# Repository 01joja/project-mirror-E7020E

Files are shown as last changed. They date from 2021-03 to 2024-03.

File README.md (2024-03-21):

# Nuttali E7020E

We built a gaming mouse in 2 months. Project in Embedded System Design at LTU (E7020E).

Members:  
* Tommy Andersson - anetom-6  (Grade 5)
* Samuel Graden   - samgra-7  (Grade 5)
* Jonas Jacobsson - jonjac-6  (Grade 5)

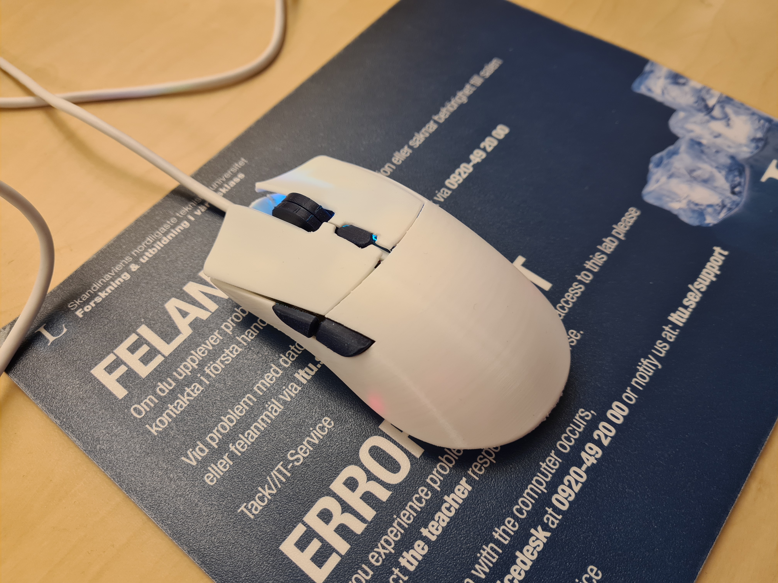
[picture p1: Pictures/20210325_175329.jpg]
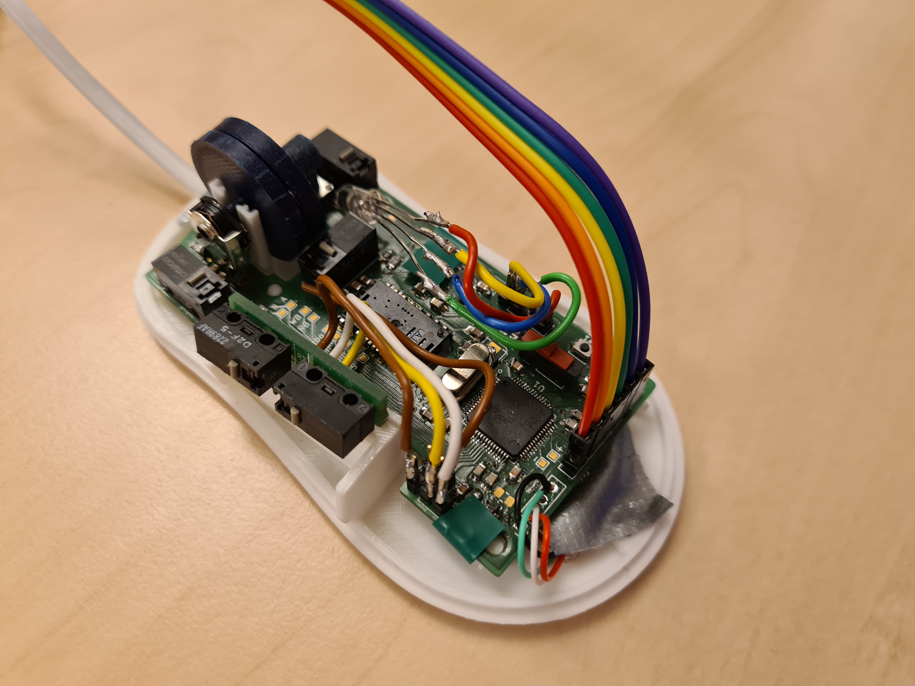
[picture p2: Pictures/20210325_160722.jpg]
 

Name *nuttali* is inspired from *Ochrotomys nuttalli* that is the *Latin* name for [golden mouse](https://en.wikipedia.org/wiki/Golden_mouse).

- Left and right buttons
- Scroll and "scroll button"
- 2 sidbutton
- Considering RGB.

Public found on: [Public](https://github.com/01joja/project-mirror-E7020E)

Course found on: [Course](https://gitlab.henriktjader.com/jonjac-6/nuttali-mirror-of-project)

## Version 0.0.2 is released!

- Side buttons, backwards and forwards now work
- RGB settings can now change mode from the DPI button
- Tested on Linux, Mac and Windows
- Created a customized report

## Version 0.0.1 is released!

The first release of our results in [E7020E](https://www.ltu.se/edu/course/E70/E7020E/E7020E-Design-av-inbyggda-system-1.67927?kursView=kursplan).

- PCB schematics and PCB board where every thing works.
- Rust code that supports basic mouse features:
  - Left, right and scroll click.  
  - Up and down scroll.
  - X and Y movement.
  - USB-communication.

### To be expected in later releases

- Fix error when connecting to some Windows devices.
- Support to change RGB for more values than 0 and 1.
- Fine tuning of sensor.
- A way to change settings by using the terminal.
- New design of scroll wheel.

[Presentation](presentation.md)

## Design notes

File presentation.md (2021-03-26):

# Nuttali Presentation

Created by: 
* Tommy Andderson, anetom-6 (Grade 5)
* Samuel Gradén, samgra-7 (Grade 5)
* Jonas Jacobsson, jonjac-6 (Grade 5)

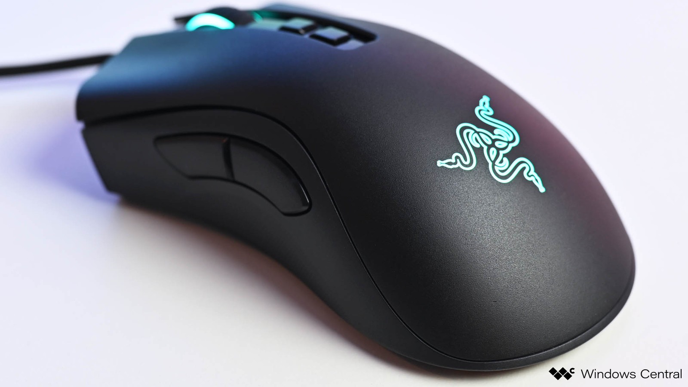
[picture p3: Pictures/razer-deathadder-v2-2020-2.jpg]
Typical gaming mouse

# Requirements specification/features
*   Work as an ordinary mouse
    * Left button
    * Right button
    * Scroll wheel (up and down)
    * Scroll wheel button
*   Create a mouse we could use every day
*   Working on Windows, Mac and Linux
*   Working RGB since it's a gaming mouse
*   Forward and backwards button
*   DPI/Turbo button
*   DPI/Turbo led
*   Changing RGB via software

## Goals

##### Achieved
- Works as an ordinary mouse 
- Create a mouse we could use every day
- Working on Windows, Mac and Linux.
- Working RGB

##### Almost 
- DPI/Turbo button 

##### Not Achieved
- DPI/Turbo Led
- Changing RGB via software

# Design
* Name _Nuttali_
  * Golden mouse in latin.
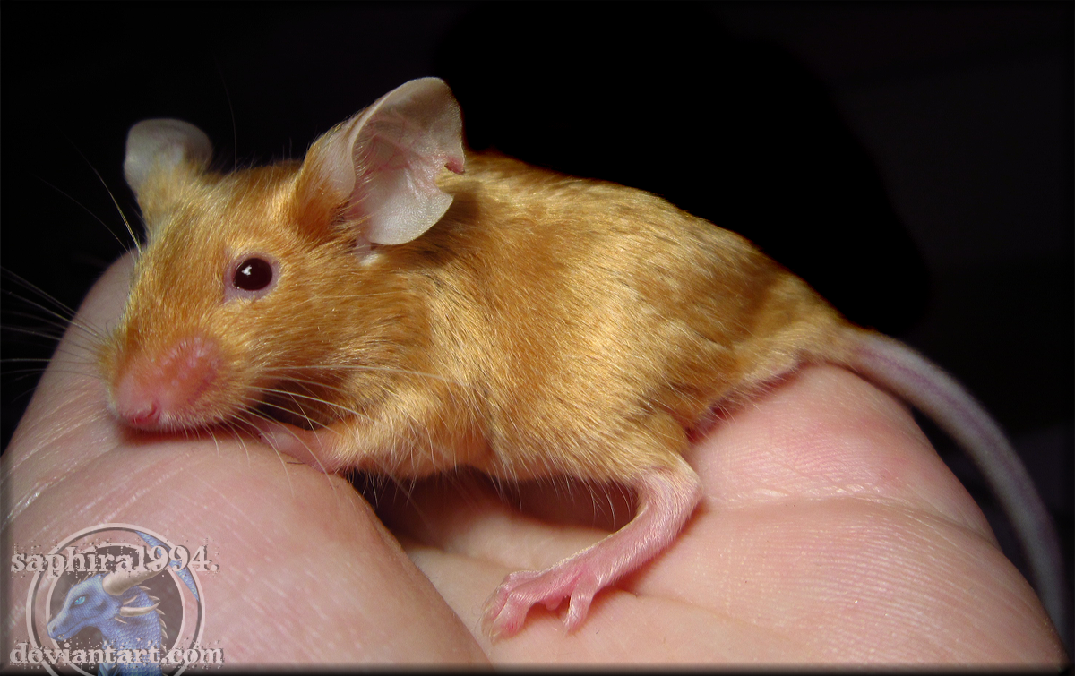
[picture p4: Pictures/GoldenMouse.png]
Golden mouse
 
* 3D-model
  * Logitech G304/G305 
  * [Original design](https://www.thingiverse.com/thing:4084764)  
* Needed changes
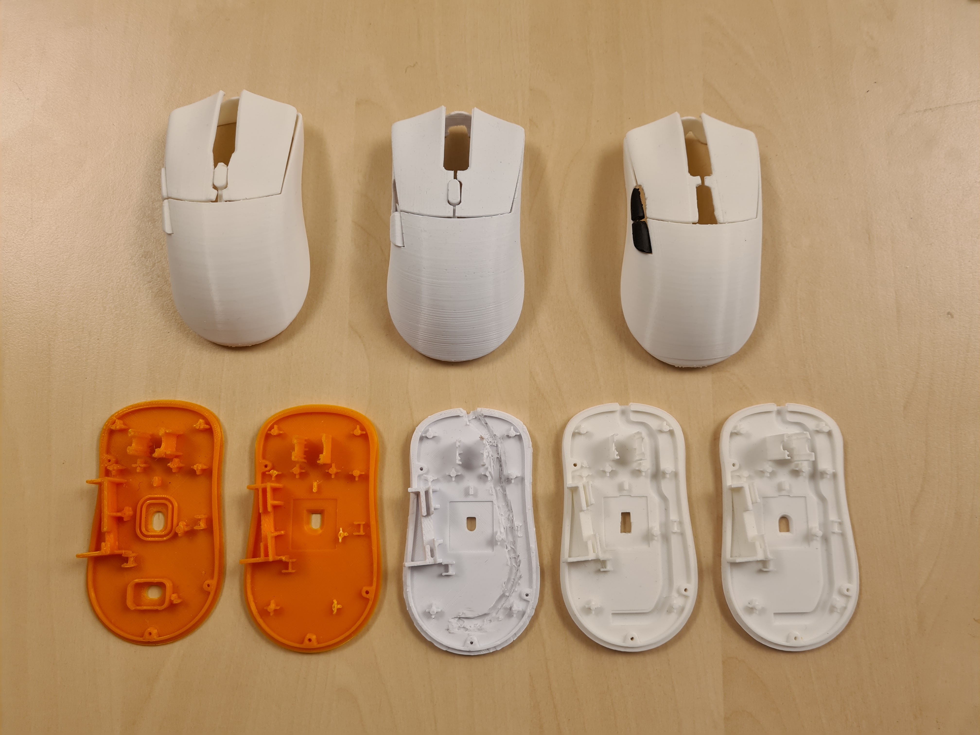
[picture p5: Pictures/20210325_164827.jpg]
All iterations

* Tools used
  * Fusion 360
  * Pursa Mini in Xp-el

# Hardware
* Design choices
* Schematic
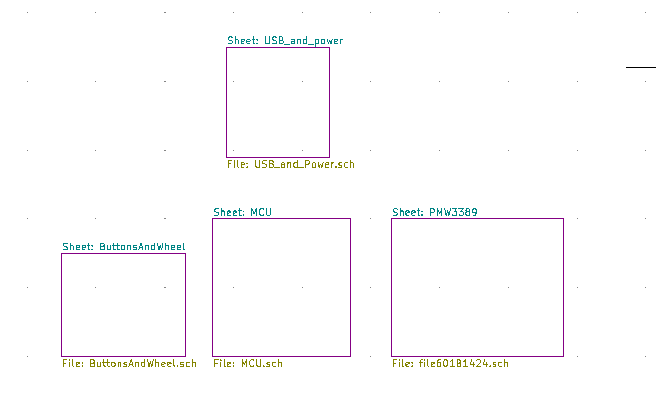
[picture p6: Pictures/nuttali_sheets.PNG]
Sheets
    * 
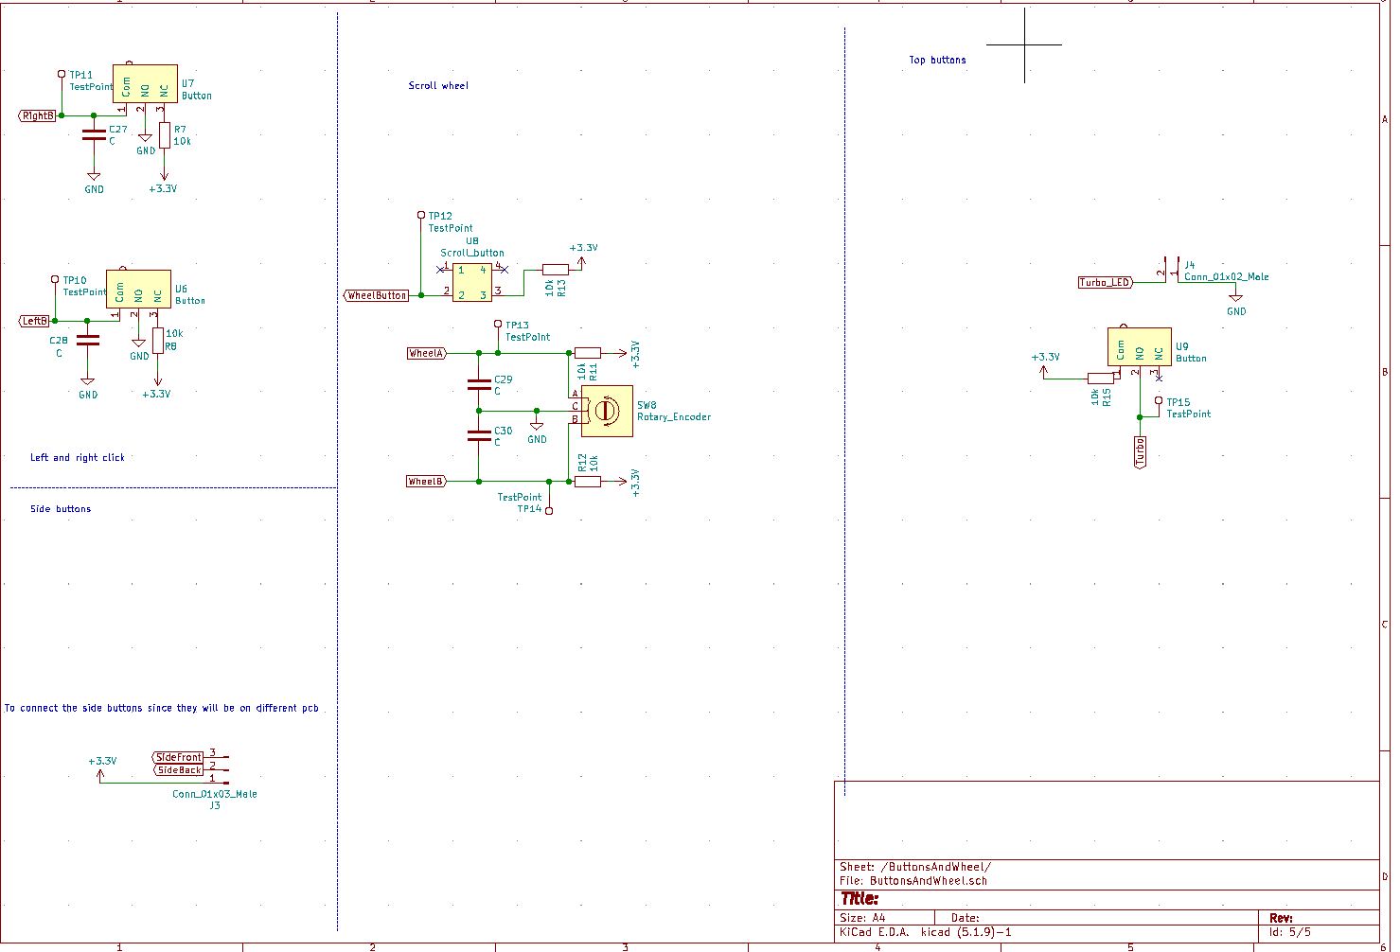
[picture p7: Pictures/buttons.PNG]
Buttons
    * 
* PCB
    * First iteration
    * Second iteration
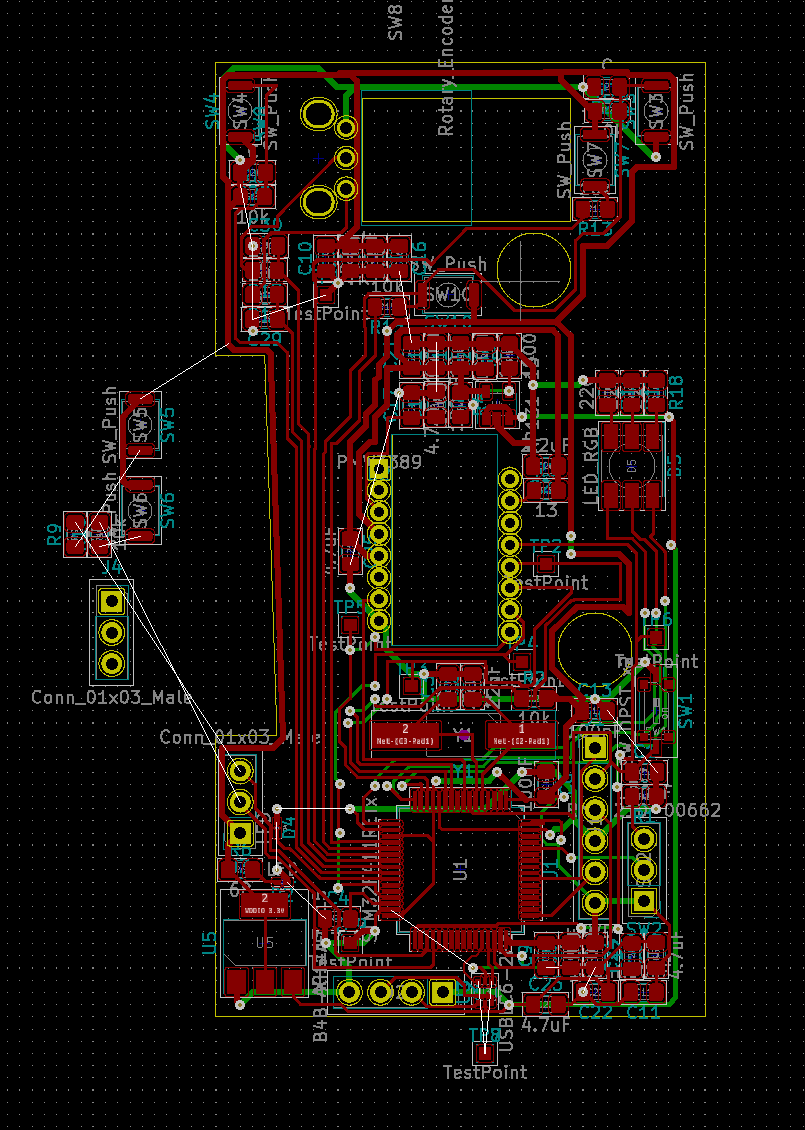
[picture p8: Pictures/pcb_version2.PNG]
Second iteration
    * 
    * Third iteration (final iteration)
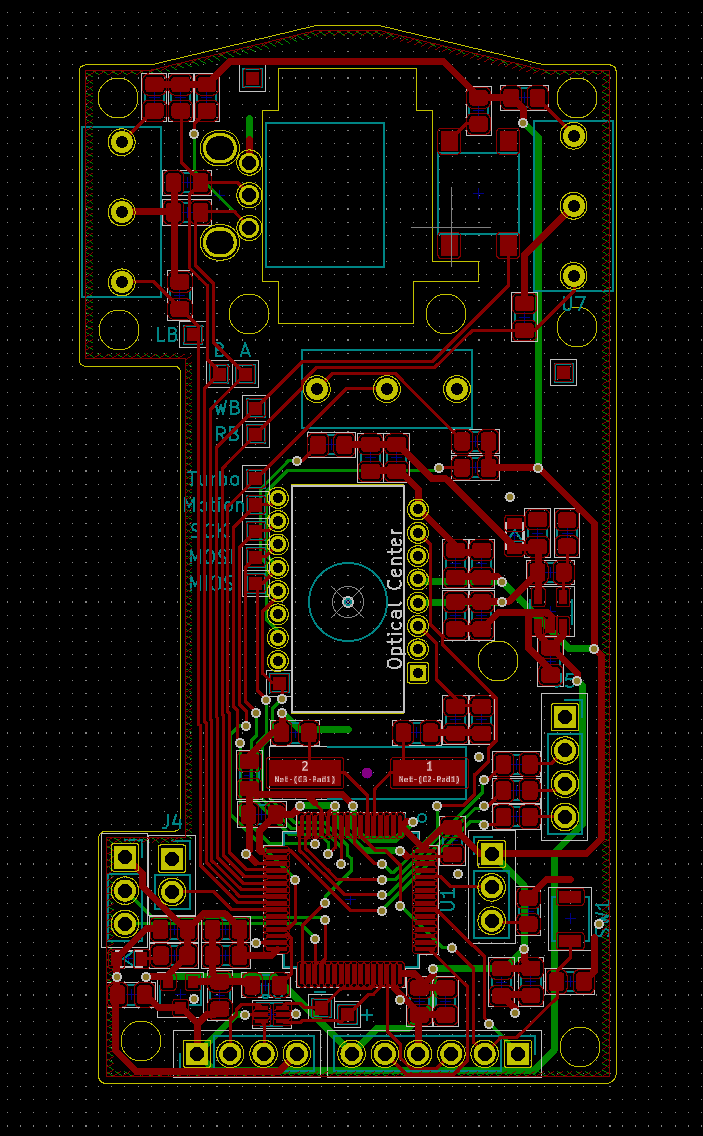
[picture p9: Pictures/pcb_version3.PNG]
Third iteration
    * 
    * Support PCB
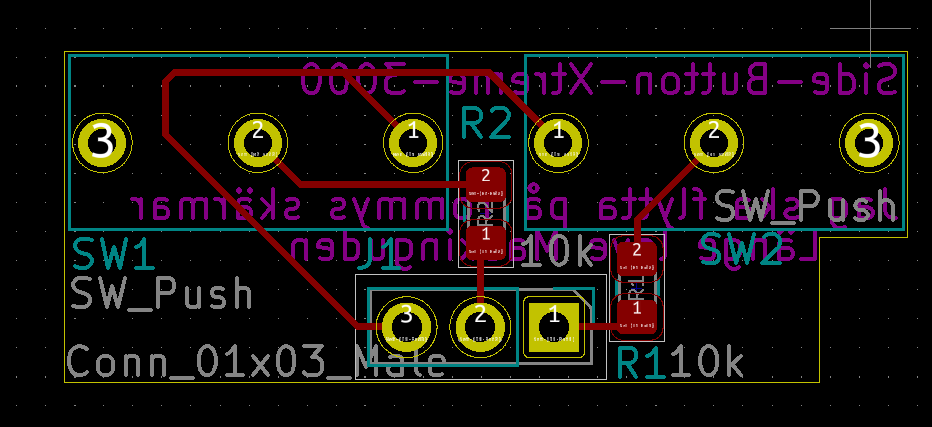
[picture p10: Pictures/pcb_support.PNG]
Support pcb
    * 
* Componets and footprints
    * Prioritized components
    * Customized footprints 
    * Design flaws
    * Under the hood
        * Under the hood 
        
# Result
Nuttali Jonas version
Nuttali Tommy version

# Software

- The computer polls the mouse.
- The mouse button 1, 2 and 3, (left, right, middle) uses HID,
- The x and y posistions gets coverted to 8 bit, and sent using HID.
- Sidebuttons are mouse button 4,5 and works as forward and backwards.

# Testing and validation

* Design test
  * _Dose it feels good?_
* Operation system test
  * Windows 
  * Mac
  * Linux
* Mouse test
  * Tested with light activity for 2 hours
  * Tested gaming
    * CS
  * Tested on mouse testsites
    * https://www.onlinemictest.com/mouse-test/
    * https://www.clickspeedtest.info/mouse-test

## What works?  

- Nearly everything works on the PCB:s.
  - All buttons can be registered.
  - Encoder for the scroll wheel.
  - Sensor.
  - RGB.
- 3D-print:
  - The shell and button alignment works most of the time.
- USB communication.
  - send left, right and scroll click.
  - send up and down scroll.
  - send movement of mouse.

## Issues

- The PCB needs a few tweaks.
  - The footprint for the ESD-protection needs to change. Right now it dose not fit.
  - The footprints for the 3.3V and 1.9 converter should be changed to fit hand soldering. Right now they are troublesome to hand solder.
  - The footprint for the crystal could be a little bit smaller. Right now it takes up too much space.

## Evaluation
##### Major
- The sensor does not always register, our primary guess for the reason is that the sensor is a bit high.
- The scroll button is a bit slow.
- Hardware debounce
- Cabel

##### Minor
- More RGB Leds
- Change the resistor for the leds
- Small changes with the 3d print.
- Bigger mouse
- Scroll Wheel.

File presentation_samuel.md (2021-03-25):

##### Software

- The computer polls the mouse.
- The mouse button 1, 2 and 3, (left, right, middle) uses HID,
- The x and y posistions gets coverted to 8 bit, and sent using HID.
- Sidebuttons are internally and iterates through a set of RBG settings.
- The DPI buttons changes the DPI internally,  

#### Evaluation
##### Major
- The sensor does not always register, our primary guess for the reason is that the sensor is a bit high.
- The scroll button is a bit slow.
- Hardware debounce

##### Minor
- More RBG Leds
- Change the resistor for the leds
- Small changes with the 3d print.
- Bigger mouse
- Scroll Wheel hole should be bigger.

#### Goals

##### Achieved
- Works as an ordinary mouse 
- Create a mouse we could use every day
- Working on Windows, Mac and Linux.
- Working RGB

##### Almost 
- DPI/Turbo button 

##### Not Achieved
- DPI/Turbo Led
- Changing RGB via software

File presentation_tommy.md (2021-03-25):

Typical gaming mouse
# Requirements specification/features
*   Work as an ordinary mouse
    * Left button
    * Right button
    * Scroll wheel (up and down)
    * Scroll wheel button
*   Create a mouse we could use every day
*   Working on Windows, Mac and Linux
*   Working RGB since it's a gaming mouse
*   Forward and backwards button
*   DPI/Turbo button
*   DPI/Turbo led
*   Changing RGB via software

# Hardware
* Design choices
* PCB
    * First iteration
    * Second iteration
    * Third iteration (final iteration)
    * Support PCB
* Componets and footprints
    * Prioritized components
    * Customized footprints 
    * Design flaws

# Testing and validation
*   Operation system test
    * Windows 
    * Mac
    * Linux
*   Mouse test
    * Tested for 1 hour
    * Tested gaming
        * Rainbow six siege
        * CS
    * Tested on mouse testsites
        * https://www.onlinemictest.com/mouse-test/
        * https://www.clickspeedtest.info/mouse-test

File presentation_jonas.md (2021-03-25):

# Jonas Del

## Shell design

The shell we found on the internet that meat our demands where of a [Logitech G305](https://www.logitechg.com/sv-se/products/gaming-mice/g305-lightspeed-wireless-gaming-mouse.910-005283.html).

[Original design](https://www.thingiverse.com/thing:4084764) and [tutorial](https://www.instructables.com/3D-Printed-Gaming-Mouse-G305/).

This mouse shell where not compatible with the PMW3398 sensor and the thickness of our PCB:s where different from the original. This also impacted the buttons and we also got some alignment issues with the side buttons and the corresponding switches. So for us to use it we needed to change a lot of things.

I was responsible for cad and 3D-printing during this project. I had no prior knowledge in any of this so it took quiet some time to get the hang of it. But it where really rewarding and made our project much better.

We used fusion 360 to change the STL files. STL is a vector based format to hold 3D models in and they need to be converted to a workable format before they are changed. It took around 1 week before I could make any changes to the model and around 1 more week until I felt comfterble using fusion 360. 

The learning curve for 3D-printing where not as steep but there where a few things to learn. But now I feel comfterble to do smaller 3D-printing and modeling in my upcoming projects. Xp-el helped me to 

I also designed the scroll wheel from scratch.

*Ask Tommy or Samuel to show the difference between them*

I may have put too much time in to the shell but it gave us a good mouse and with some more changes to the design it could be a good mouse.

## Design of hardware

The hardware design where somewhat inspired form the [G305 PCB](https://www.reddit.com/r/MouseReview/comments/isist1/trimming_guide_for_the_g305_pcb_as_used_in_my/). At least where the buttons goes, the location of the scroll wheel and where the sensor is mounted. Also some of the screw holes came directly from this design. But most of the general layout where things Tommy figured out.

## Testing and validation

During the design of the hardware the only way to test something where with the built in test in KiCad.

Later when we where soldering everything we used the test points in the design frequently. Writing labels next to the test point where really helpful. This made the soldering of the mcu really smooth. Just touch the pin and the test point and you know that you have connection. Touch the pins next to the right pin and you know if two pins are soldered together. Using this way of testing all mcu:s worked first time we programmed them.

The testing and validation of shell and buttons has been *"Dose it feel good?"* and letting our classmates test the mouse.

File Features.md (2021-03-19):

- Höger och vänster knapptryck
- Scroll
- Scrollknapp
- Fram och bakknapp på höger sida.
- Överväger en RGB-LEDs

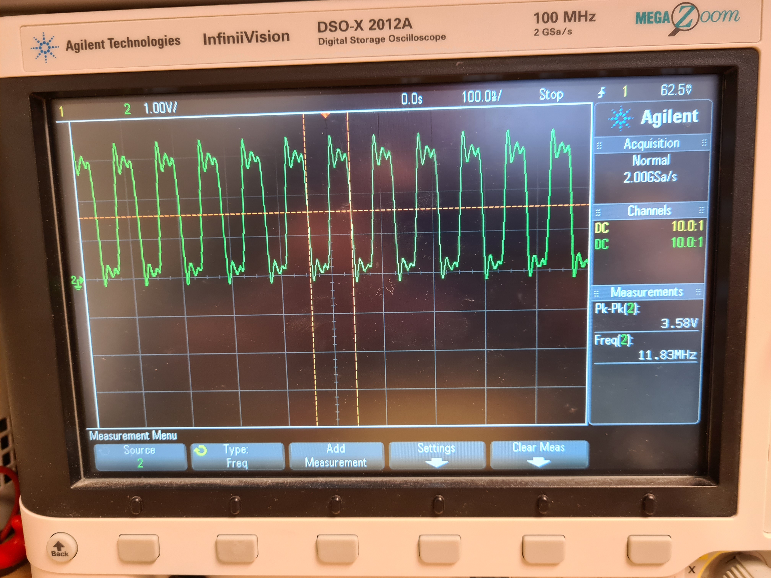
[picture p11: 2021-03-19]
nuttali/examples/pictures/examples_bare_6_48mhz_low_speed.jpg

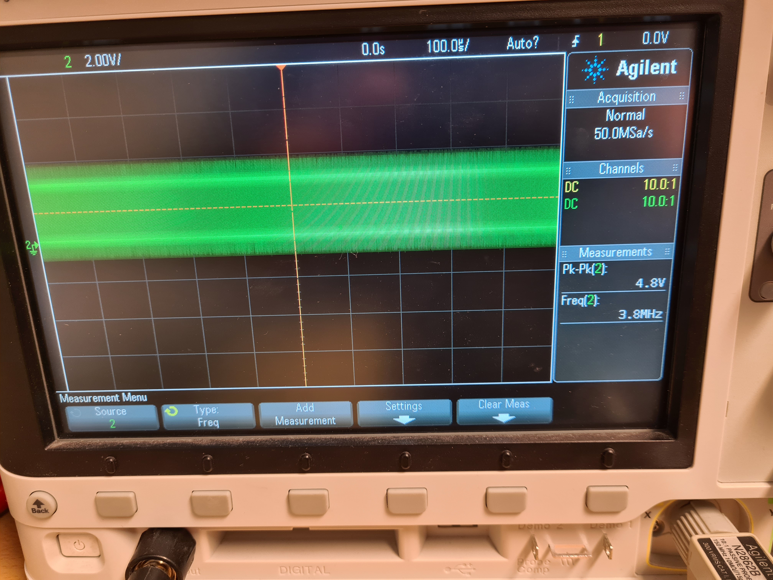
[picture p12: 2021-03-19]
nuttali/examples/pictures/pictures_bare_6_16mhz_high_speed.jpg

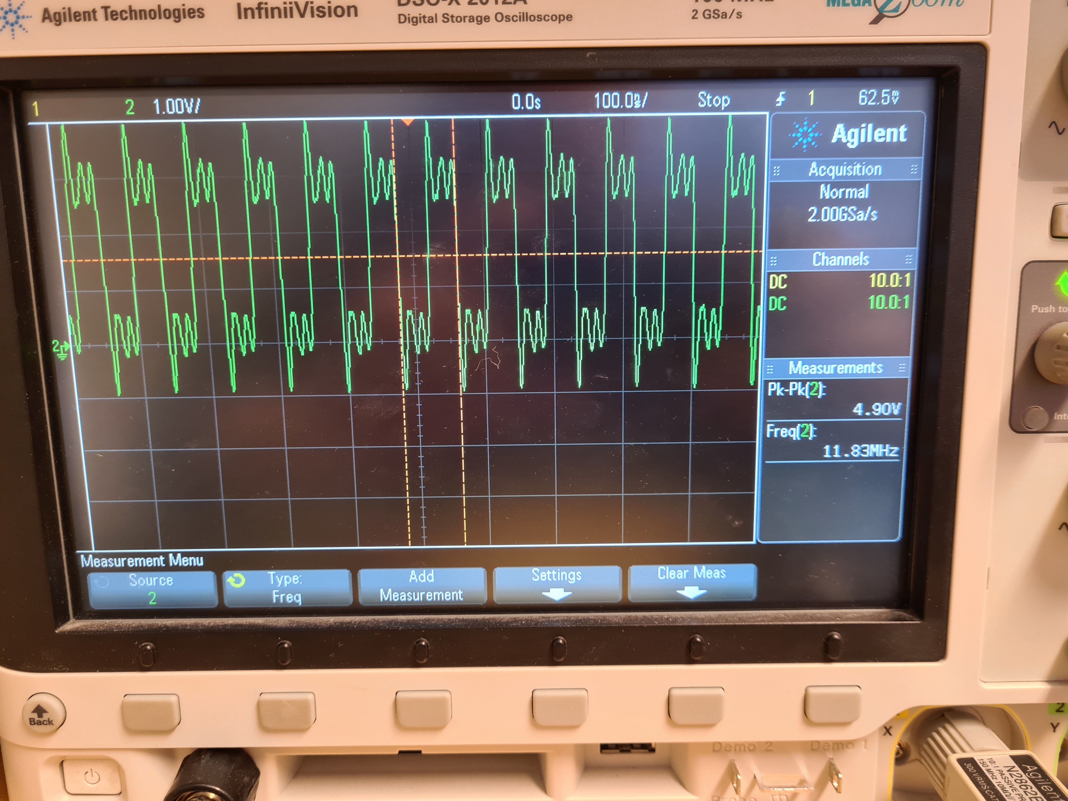
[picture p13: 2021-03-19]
nuttali/examples/pictures/pictures_bare_6_48mhz_high_speed.jpg

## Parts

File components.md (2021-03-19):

[Crystal](https://www.elfa.se/sv/kristall-tht-16mhz-iqd-lfxtal003240/p/17451701?queryFromSuggest=true) 5.18 SEK  
[MCU](https://www.elfa.se/sv/microcontroller-32bit-512kb-lqfp-st-stm32f411ret6/p/30170741?queryFromSuggest=true) 66.63 SEK  
[LED](https://www.elfa.se/en/smd-led-645nm-0805-65cd-30ma-kingbright-kptd-2012surck/p/30118951) 0.9595 SEK  

[6-pins](https://www.elfa.se/en/straight-male-pcb-header-through-hole-rows-contacts-54mm-pitch-rnd-connect-rnd-205-00627/p/30093647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) 0,8435 SEK

Insted of USB-C  
[Straight 4-pin Header](https://www.elfa.se/en/pin-header-single-row-straight-pin-header-plug-positions-5mm-jst-b4b-xh-lf-sn/p/14301996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) 2.01 SEK  
[Mount](https://www.elfa.se/en/crimp-housing-receptacle-socket-positions-5mm-jst-xhp/p/14302034) 1.26 SEK  
[Any old USB-cable](https://www.elfa.se/en/usb-plug-to-usb-mini-pin-plug-cable-8m-black-rnd-connect-rnd-765-00049/p/30125757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) 18.40 SEK  
[Reset button](https://www.elfa.se/en/subminiature-tactile-switch-b3u-1no-5n-3mm-omron-electronic-components-b3u-1000p/p/30171080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) 8.14 SEK
[Or Slide button for reset and boot0](https://www.elfa.se/en/slide-switch-1co-on-on-pcb-through-hole-rnd-components-rnd-210-00662/p/30161239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) 13.20 SEK  

[Mouse Encoder](https://se.rs-online.com/web/p/mechanical-rotary-encoders/7295545) 9.62 SEK  
[Mouse wheel](https://www.aliexpress.com/item/4001130734583.html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,searchweb201602_,searchweb201603_)  

[Mouse Buttons](https://www.elfa.se/en/micro-switch-d2f-5a-1co-47n-pin-plunger-omron-electronic-components-d2f/p/30156583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) 6.84 SEK  
[Scroll Buttons](https://www.elfa.se/en/tactile-switch-1no-on-off-53n-5x6mm-wuerth-elektronik-434121050836/p/30142305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) 6.84 SEK

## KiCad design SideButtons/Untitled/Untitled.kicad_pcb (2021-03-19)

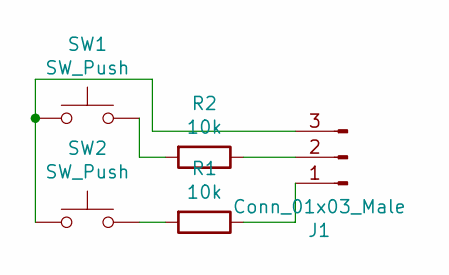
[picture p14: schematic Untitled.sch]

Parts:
J1: Conn_01x03_Male; PinHeader_1x03_P2.54mm_Vertical
R1, R2: 10k; R_0805_2012Metric_Pad1.20x1.40mm_HandSolder
SW1, SW2: SW_Push; D2F-5

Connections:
unnamed: J1.1, R1.1
unnamed: J1.2, R2.1
unnamed: J1.3, SW1.1, SW2.1
unnamed: R1.2, SW2.2
unnamed: R2.2, SW1.2

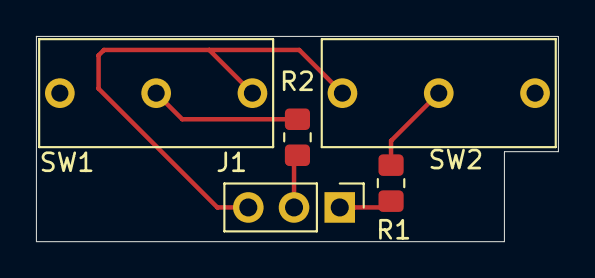
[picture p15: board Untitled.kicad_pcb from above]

Board: 2 copper layers, 29.0 x 11.4 mm, 5 parts (0 on the bottom side), 5 nets.

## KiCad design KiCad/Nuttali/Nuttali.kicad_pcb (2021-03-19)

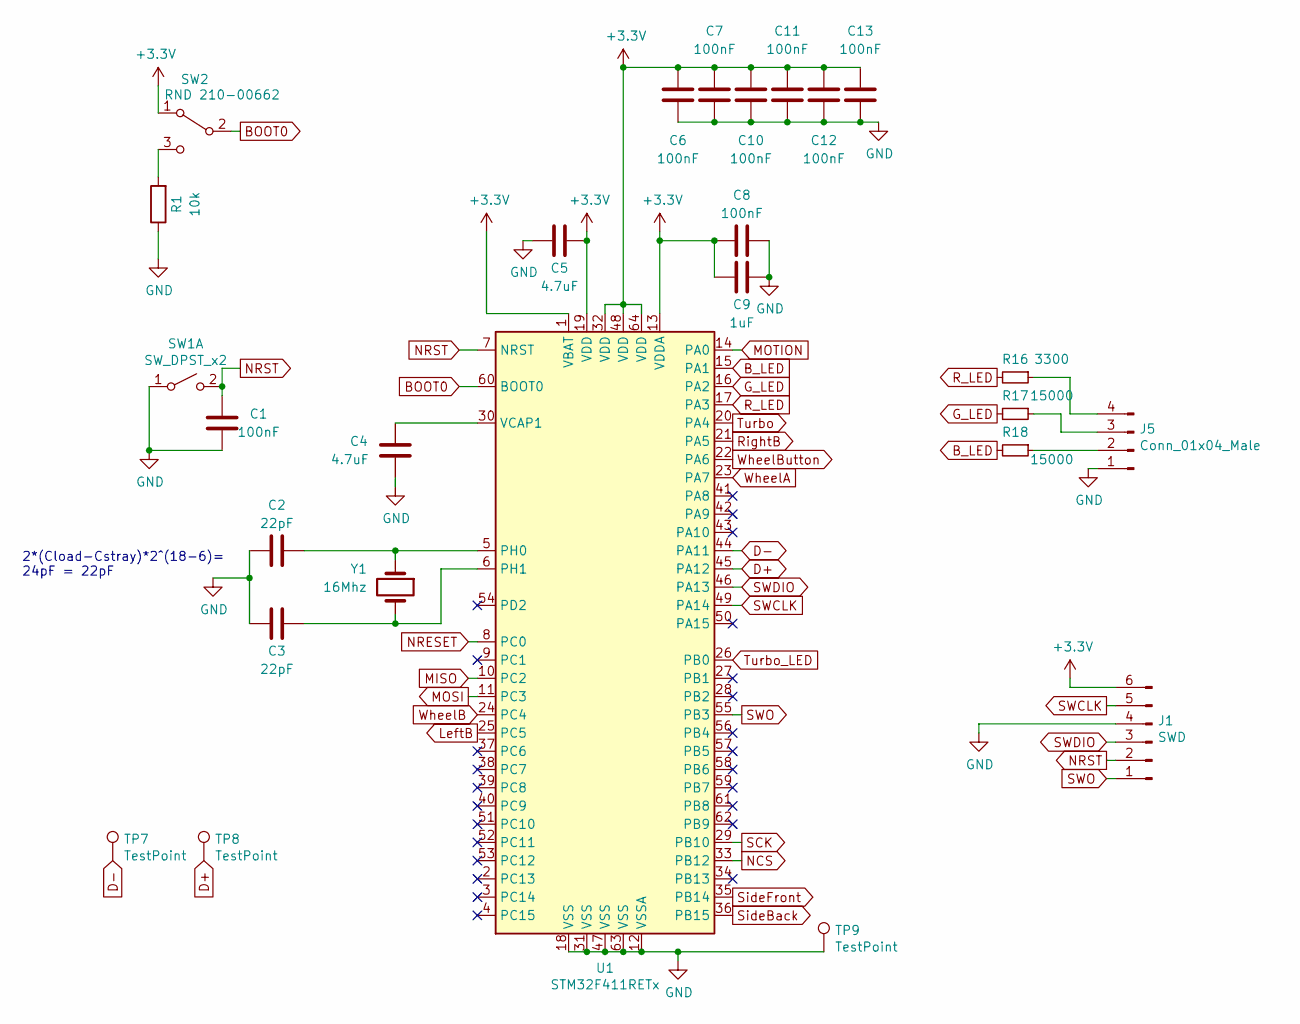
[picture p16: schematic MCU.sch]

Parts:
C1, C6, C7, C8, C10, C11, C12, C13: 100nF; C_0805_2012Metric_Pad1.18x1.45mm_HandSolder
C2, C3: 22pF; C_0805_2012Metric_Pad1.18x1.45mm_HandSolder
C4, C5: 4.7uF; C_0805_2012Metric_Pad1.18x1.45mm_HandSolder
C9: 1uF; C_0805_2012Metric_Pad1.18x1.45mm_HandSolder
J1: SWD; PinHeader_1x06_P2.54mm_Vertical
J5: Conn_01x04_Male; PinSocket_1x04_P2.54mm_Vertical
R1: 10k; R_0805_2012Metric_Pad1.20x1.40mm_HandSolder
R16: 3300; R_0805_2012Metric_Pad1.20x1.40mm_HandSolder
R17, R18: 15000; R_0805_2012Metric_Pad1.20x1.40mm_HandSolder
SW1: SW_DPST_x2; SW_SPST_B3U-1000P
SW2: RND 210-00662; PinHeader_1x03_P2.54mm_Vertical
TP7, TP8, TP9: TestPoint; TestPoint_Pad_1.0x1.0mm
U1: STM32F411RETx; LQFP-64_10x10mm_P0.5mm
Y1: 16Mhz; Crystal_SMD_0603-2Pin_6.0x3.5mm_HandSoldering

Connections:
+3V3: C5.1, C6.2, C7.2, C8.2, C9.2, C10.2, C11.1, C12.1, C13.1, J1.6, SW2.1 (A), U1.1 (VBAT), U1.13 (VDDA), U1.19 (VDD), U1.32 (VDD), U1.48 (VDD), U1.64 (VDD); also elsewhere on the board
BOOT0: SW2.2 (B), U1.60 (BOOT0)
B_LED: R18.2, U1.15 (PA1)
D+: TP8.1, U1.45 (PA12); also elsewhere on the board
D-: TP7.1, U1.44 (PA11); also elsewhere on the board
GND: C1.2, C2.2, C3.2, C4.1, C5.2, C6.1, C7.1, C8.1, C9.1, C10.1, C11.2, C12.2, C13.2, J1.4, J5.1, R1.1, SW1.1 (A), TP9.1, U1.12 (VSSA), U1.18 (VSS), U1.31 (VSS), U1.47 (VSS), U1.63 (VSS); also elsewhere on the board
G_LED: R17.2, U1.16 (PA2)
LeftB: U1.25 (PC5); also elsewhere on the board
MISO: U1.10 (PC2); also elsewhere on the board
MOSI: U1.11 (PC3); also elsewhere on the board
MOTION: U1.14 (PA0); also elsewhere on the board
NCS: U1.33 (PB12); also elsewhere on the board
NRESET: U1.8 (PC0); also elsewhere on the board
NRST: C1.1, J1.2, SW1.2 (B), U1.7 (NRST)
unnamed: C2.1, U1.5 (PH0), Y1.1
unnamed: C3.1, U1.6 (PH1), Y1.2
unnamed: C4.2, U1.30 (VCAP1)
unnamed: J5.2, R18.1
unnamed: J5.3, R17.1
unnamed: J5.4, R16.1
unnamed: R1.2, SW2.3 (C)
R_LED: R16.2, U1.17 (PA3)
RightB: U1.21 (PA5); also elsewhere on the board
SCK: U1.29 (PB10); also elsewhere on the board
SWCLK: J1.5, U1.49 (PA14)
SWDIO: J1.3, U1.46 (PA13)
SWO: J1.1, U1.55 (PB3)
SideBack: U1.36 (PB15); also elsewhere on the board
SideFront: U1.35 (PB14); also elsewhere on the board
Turbo: U1.20 (PA4); also elsewhere on the board
Turbo_LED: U1.26 (PB0); also elsewhere on the board
WheelA: U1.23 (PA7); also elsewhere on the board
WheelB: U1.24 (PC4); also elsewhere on the board
WheelButton: U1.22 (PA6); also elsewhere on the board

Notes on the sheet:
2*(Cload-Cstray)*2^(18-6)= 24pF = 22pF

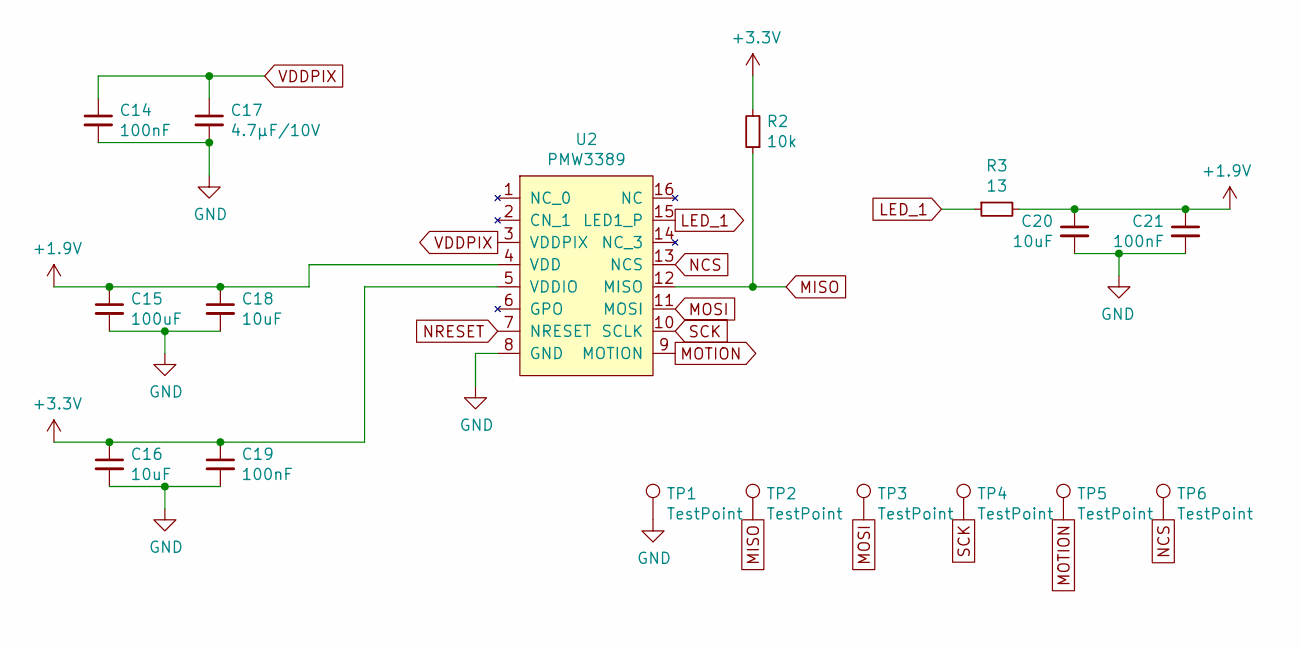
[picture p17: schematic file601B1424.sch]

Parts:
C14, C19, C21: 100nF; C_0805_2012Metric_Pad1.18x1.45mm_HandSolder
C15: 100uF; C_0805_2012Metric_Pad1.18x1.45mm_HandSolder
C16, C18, C20: 10uF; C_0805_2012Metric_Pad1.18x1.45mm_HandSolder
C17: 4.7μF/10V; C_0805_2012Metric_Pad1.18x1.45mm_HandSolder
R2: 10k; R_0805_2012Metric_Pad1.20x1.40mm_HandSolder
R3: 13; R_0805_2012Metric_Pad1.20x1.40mm_HandSolder
TP1, TP2, TP3, TP4, TP5, TP6: TestPoint; TestPoint_Pad_1.0x1.0mm
U2: PMW3389; PMW3389DM-T3QU

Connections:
+1V0: C15.1, C18.1, C20.1, C21.1, R3.2, U2.4 (VDD); also elsewhere on the board
+3V3: C16.1, C19.1, R2.2, U2.5 (VDDIO); also elsewhere on the board
GND: C14.2, C15.2, C16.2, C17.2, C18.2, C19.2, C20.2, C21.2, TP1.1, U2.8 (GND); also elsewhere on the board
LED_1: R3.1, U2.15 (LED1_P)
MISO: R2.1, TP2.1, U2.12 (MISO); also elsewhere on the board
MOSI: TP3.1, U2.11 (MOSI); also elsewhere on the board
MOTION: TP5.1, U2.9 (MOTION); also elsewhere on the board
NCS: TP6.1, U2.13 (NCS); also elsewhere on the board
NRESET: U2.7 (NRESET); also elsewhere on the board
SCK: TP4.1, U2.10 (SCLK); also elsewhere on the board
VDDPIX: C14.1, C17.1, U2.3 (VDDPIX)

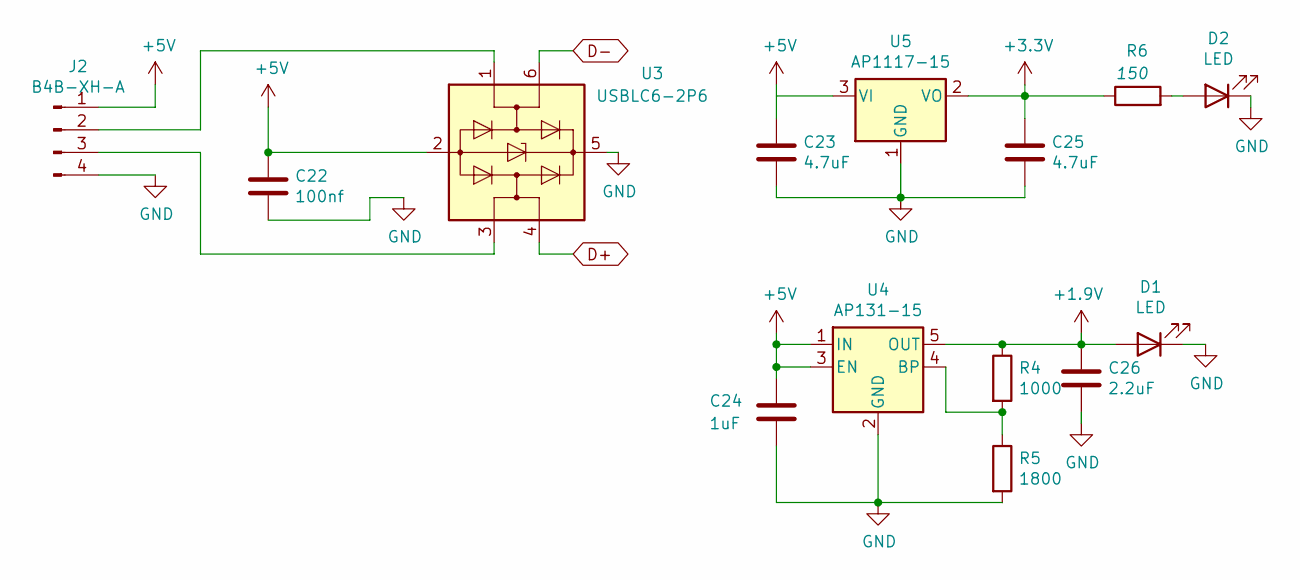
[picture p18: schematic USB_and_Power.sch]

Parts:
C22: 100nf; C_0805_2012Metric_Pad1.18x1.45mm_HandSolder
C23, C25: 4.7uF; C_0805_2012Metric_Pad1.18x1.45mm_HandSolder
C24: 1uF; C_0805_2012Metric_Pad1.18x1.45mm_HandSolder
C26: 2.2uF; C_0805_2012Metric_Pad1.18x1.45mm_HandSolder
D1, D2: LED
J2: B4B-XH-A; PinHeader_1x04_P2.54mm_Vertical
R4: 1000; R_0805_2012Metric_Pad1.20x1.40mm_HandSolder
R5: 1800; R_0805_2012Metric_Pad1.20x1.40mm_HandSolder
R6: 150; R_0805_2012Metric_Pad1.20x1.40mm_HandSolder
U3: USBLC6-2P6; SOT-666_ESD
U4: AP131-15; SOT-23-5
U5: AP1117-15; SOT-23

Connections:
+1V0: C26.1, D1.2 (A), R4.1, U4.5 (OUT); also elsewhere on the board
+3V3: C25.1, R6.1, U5.2 (VO); also elsewhere on the board
+5V: C22.1, C23.1, C24.1, J2.1, U3.2 (GND), U4.1 (IN), U4.3 (EN), U5.3 (VI)
D+: U3.4 (I/O2); also elsewhere on the board
D-: U3.6 (I/O1); also elsewhere on the board
GND: C22.2, C23.2, C24.2, C25.2, C26.2, D1.1 (K), D2.1 (K), J2.4, R5.2, U3.5 (VBUS), U4.2 (GND), U5.1 (GND); also elsewhere on the board
unnamed: D2.2 (A), R6.2
unnamed: J2.2, U3.1 (I/O1)
unnamed: J2.3, U3.3 (I/O2)
unnamed: R4.2, R5.1, U4.4 (BP)

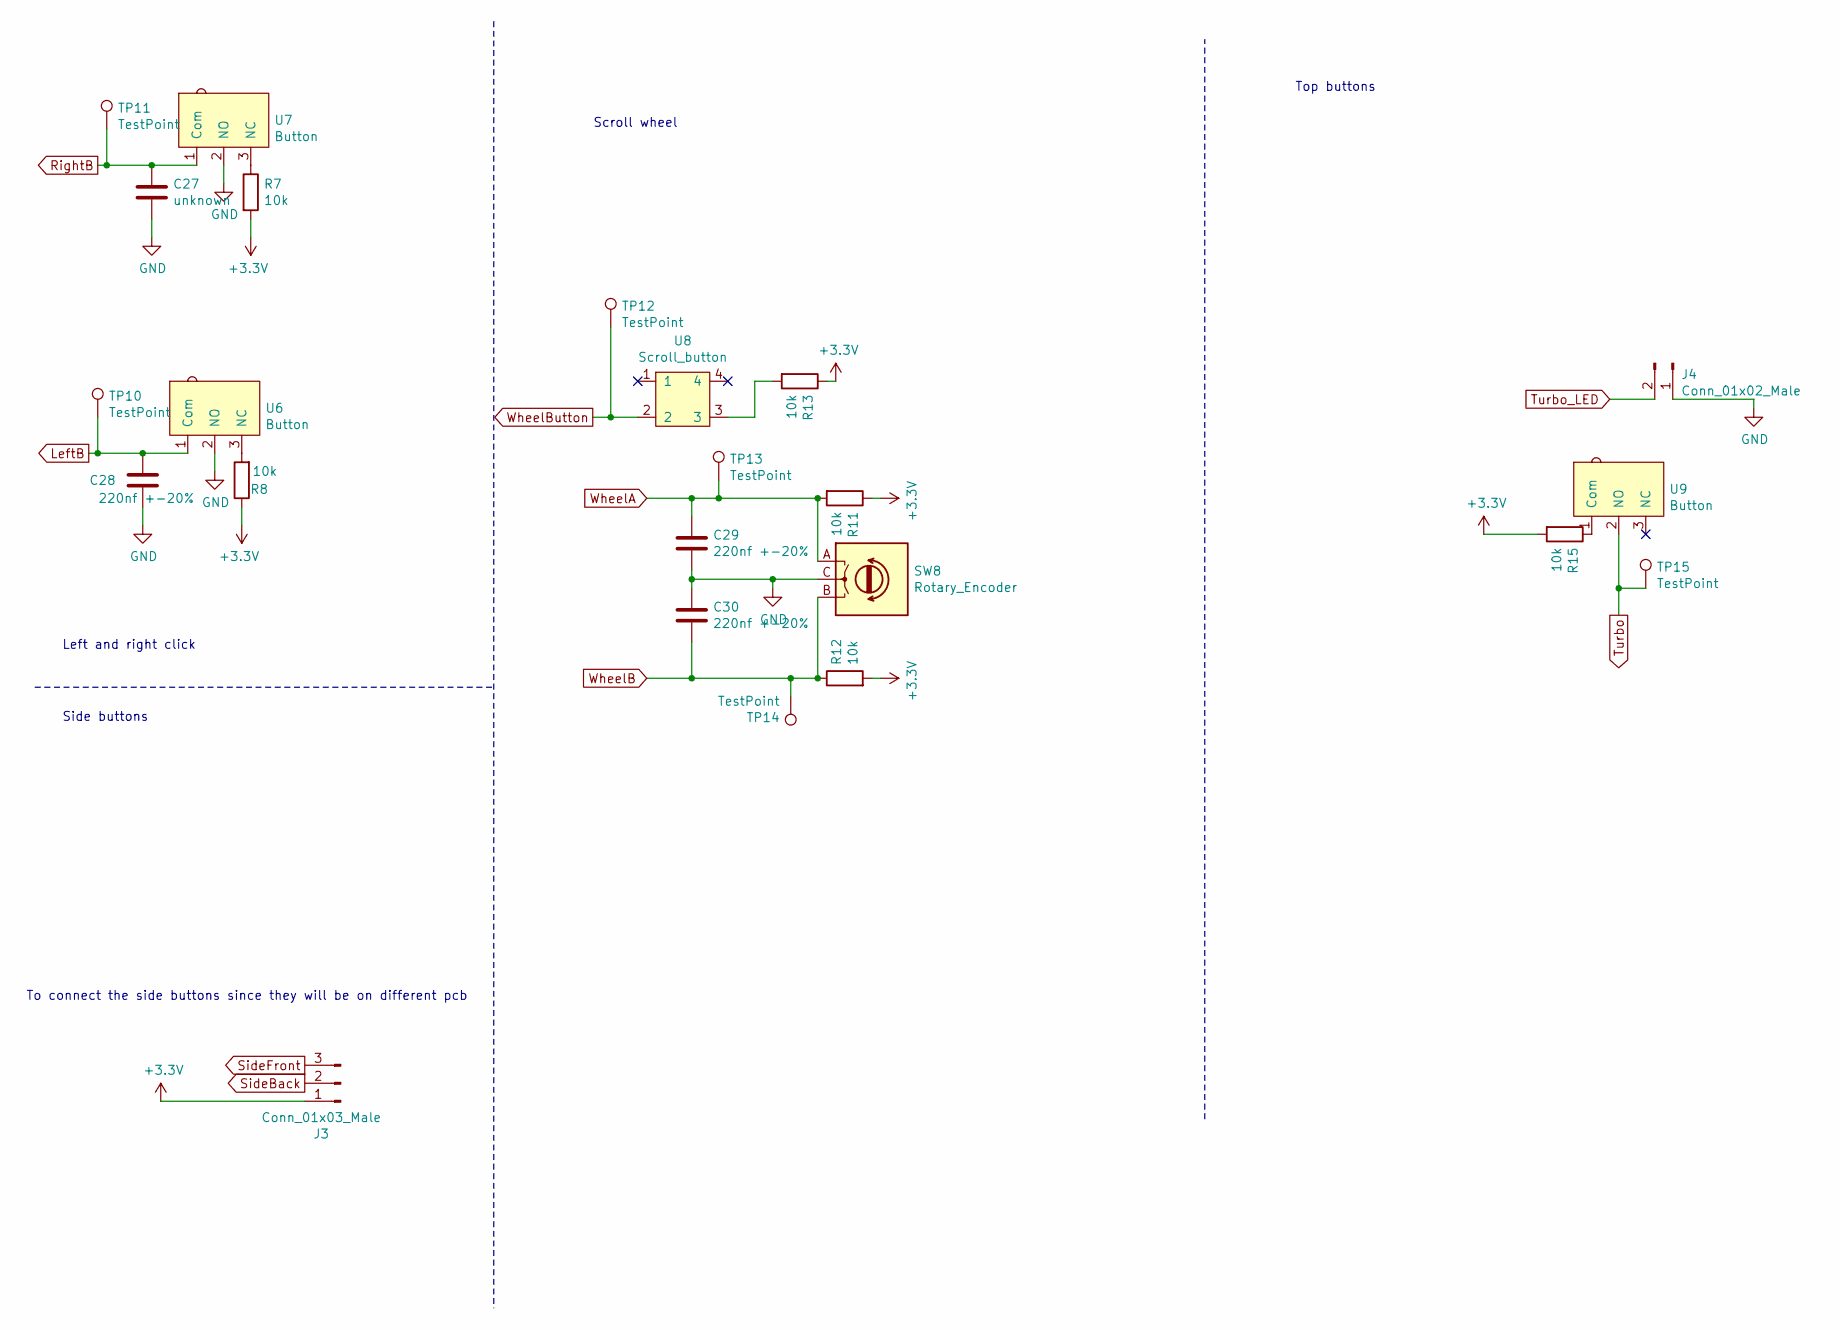
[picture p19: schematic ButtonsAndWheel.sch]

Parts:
C27: unknown; C_0805_2012Metric_Pad1.18x1.45mm_HandSolder
C28, C29, C30: 220nf +-20%; C_0805_2012Metric_Pad1.18x1.45mm_HandSolder
J3: Conn_01x03_Male; PinSocket_1x03_P2.54mm_Vertical
J4: Conn_01x02_Male; PinSocket_1x02_P2.54mm_Vertical
R7, R8, R11, R12, R13, R15: 10k; R_0805_2012Metric_Pad1.20x1.40mm_HandSolder
SW8: Rotary_Encoder; Encoder
TP10, TP11, TP12, TP13, TP14, TP15: TestPoint; TestPoint_Pad_1.0x1.0mm
U6, U7, U9: Button; D2F-5
U8: Scroll_button

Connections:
+3V3: J3.1, R7.2, R8.1, R11.1, R12.2, R13.1, R15.2; also elsewhere on the board
GND: C27.2, C28.2, C29.2, C30.1, J4.1, SW8.C, U6.2 (NO), U7.2 (NO); also elsewhere on the board
LeftB: C28.1, TP10.1, U6.1 (Com); also elsewhere on the board
unnamed: R7.1, U7.3 (NC)
unnamed: R8.2, U6.3 (NC)
unnamed: R13.2, U8.3
unnamed: R15.1, U9.1 (Com)
RightB: C27.1, TP11.1, U7.1 (Com); also elsewhere on the board
SideBack: J3.2; also elsewhere on the board
SideFront: J3.3; also elsewhere on the board
Turbo: TP15.1, U9.2 (NO); also elsewhere on the board
Turbo_LED: J4.2; also elsewhere on the board
WheelA: C29.1, R11.2, SW8.A, TP13.1; also elsewhere on the board
WheelB: C30.2, R12.1, SW8.B, TP14.1; also elsewhere on the board
WheelButton: TP12.1, U8.2; also elsewhere on the board

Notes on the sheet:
Left and right click
Side buttons
Scroll wheel
Top buttons
To connect the side buttons since they will be on different pcb

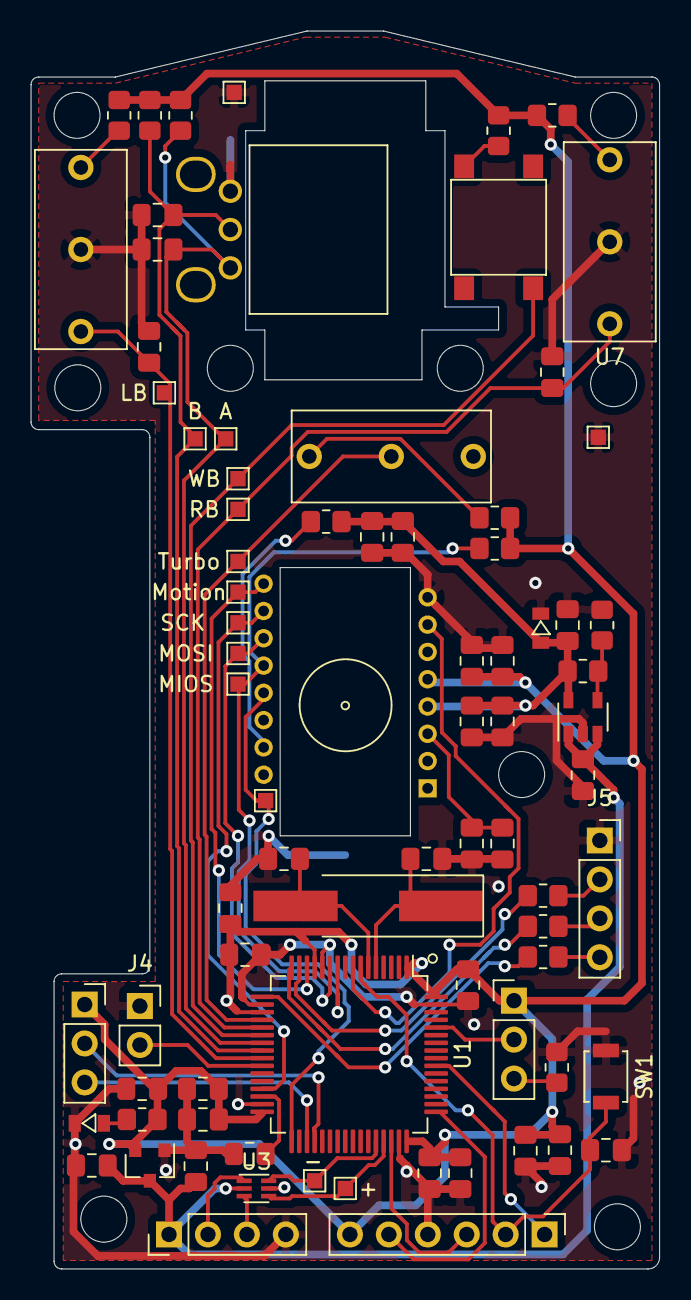
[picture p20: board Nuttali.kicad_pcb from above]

Board: 2 copper layers, 41.0 x 80.8 mm, 80 parts (0 on the bottom side), 46 nets.

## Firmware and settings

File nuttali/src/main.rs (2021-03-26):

//Work made by J, Jacobsson, T. Andersson and S. Gradén.
//Tested and valideted on:
//Windows - Lenovo Yoga 7 series
//Mac - Apple MacBook Pro Model A2141 EMC 3347
//TODO:
//Forward and back buttons should work as normal buttons.
//RGB should be able to be configured in the computer.

#![no_main]
#![no_std]

//Needed to create custom made hid reports
use usbd_hid::hid_class::HIDClass;
use usbd_hid::descriptor::SerializedDescriptor;
use serde::ser::{Serialize, Serializer, SerializeTuple};
use usbd_hid::descriptor::AsInputReport;
use usbd_hid::descriptor::gen_hid_descriptor;

//Cortex things from per
//use cortex_m::{asm::delay, peripheral::DWT};
use stm32f4xx_hal::{
    //dwt::Dwt,
    gpio::Speed,
    //Look at resources to see what pin belongs to what.
    gpio::{gpioa::{PA1, PA2, PA3, PA4, PA5, PA6, PA7},
        gpiob::{PB10, PB12, PB14,PB15},
        gpioc::{PC2, PC3, PC4, PC5},
        Alternate, Output, PushPull, Input, PullDown,// PullUp, 
    },
    //rcc::Clocks,
    spi::Spi,
    //stm32,
    otg_fs::{UsbBus, UsbBusType, USB}, //USB
    prelude::*,
};
use usb_device::{bus::UsbBusAllocator, prelude::*};

use embedded_hal::spi::MODE_3;
//use rtic::cyccnt::{Instant, U32Ext as _};
use panic_rtt_target as _;
use rtt_target::{rprintln, rtt_init_print};

use app::{
    pmw3389::{self, Register},
    DwtDelay,
};

//Some settings for the sensor.
type PMW3389T = pmw3389::Pmw3389<
    Spi<
        stm32f4xx_hal::stm32::SPI2,
        (
            PB10<Alternate<stm32f4xx_hal::gpio::AF5>>,
            PC2<Alternate<stm32f4xx_hal::gpio::AF5>>,
            PC3<Alternate<stm32f4xx_hal::gpio::AF5>>,
        ),
    >,
    PB12<Output<PushPull>>,
>;

//Report for USB.
#[gen_hid_descriptor(
    (collection = APPLICATION, usage_page = GENERIC_DESKTOP, usage = MOUSE) = {
        (collection = PHYSICAL, usage = POINTER) = {
            (usage_page = BUTTON, usage_min = 0x01, usage_max = 0x05) = {
                #[packed_bits 5] #[item_settings data,variable,absolute] buttons=input;
            };
            (usage_page = GENERIC_DESKTOP,) = {
                (usage = X,) = {
                    #[item_settings data,variable,relative] x=input;
                };
                (usage = Y,) = {
                    #[item_settings data,variable,relative] y=input;
                };
                (usage = WHEEL,) = {
                    #[item_settings data,variable,relative] wheel=input;
                };
            };
        };
    }
)]
pub struct NuttaliReport {
    pub buttons: u8,
    pub x: i8,
    pub y: i8,
    pub wheel: i8, // Scroll down (negative) or up (positive) this many units
}

#[rtic::app(device = stm32f4xx_hal::stm32, peripherals = true)]
const APP: () = {
    struct Resources {
        // late resources
        // Leds
        led_blue: PA1<Output<PushPull>>,
        led_red:  PA3<Output<PushPull>>,
        led_green: PA2<Output<PushPull>>,

        // Buttons
        dpi_button: PA4<Input<PullDown>>,
        right_button: PA5<Input<PullDown>>,
        scroll_button: PA6<Input<PullDown>>,
        backward_button: PB15<Input<PullDown>>,
        forward_button: PB14<Input<PullDown>>,
        left_button: PC5<Input<PullDown>>,

        // Scroll
        scroll_B: PC4<Input<PullDown>>,
        scroll_A: PA7<Input<PullDown>>,

        // USB
        hid: HIDClass<'static, UsbBusType>,
        usb_dev: UsbDevice<'static, UsbBus<USB>>,
        
        //Sensor
        pmw3389: PMW3389T, 
    }

    #[init]
    fn init(mut ctx: init::Context) -> init::LateResources {
        static mut EP_MEMORY: [u32; 1024] = [0; 1024];
        static mut USB_BUS: Option<UsbBusAllocator<UsbBusType>> = None;

        rtt_init_print!();
        rprintln!("init");
        
        //Split all needed gpioa so that we can access every single pin.
        let gpioa = ctx.device.GPIOA.split();
        let gpiob = ctx.device.GPIOB.split();
        let gpioc = ctx.device.GPIOC.split();

        // Set up the system clock.
        let rcc = ctx.device.RCC.constrain();
        let _clocks = rcc.cfgr.sysclk(48.mhz()).require_pll48clk().freeze();

        // Initialize (enable) the monotonic timer (CYCCNT)
        ctx.core.DCB.enable_trace();
        ctx.core.DWT.enable_cycle_counter();

        // Leds
        let led_red = gpioa.pa3.into_push_pull_output();
        let led_green = gpioa.pa2.into_push_pull_output();
        let led_blue = gpioa.pa1.into_push_pull_output();
        
        // Buttons
        let left_button = gpioc.pc5.into_pull_down_input();
        let right_button = gpioa.pa5.into_pull_down_input();
        let scroll_button = gpioa.pa6.into_pull_down_input();
        let backward_button = gpiob.pb15.into_pull_down_input();
        let forward_button = gpiob.pb14.into_pull_down_input();
        let dpi_button = gpioa.pa4.into_pull_down_input();

        //Scroll
        let scroll_A = gpioa.pa7.into_pull_down_input();
        let scroll_B = gpioc.pc4.into_pull_down_input();

        // Sensor Init
        // ||||||||||
        // \/\/\/\/\/
        let mut core = ctx.core;

        // Initialize (enable) the monotonic timer (CYCCNT)
        core.DCB.enable_trace();
        core.DWT.enable_cycle_counter();

        // setup clocks Duplicate code
        //let rcc = ctx.device.RCC.constrain();
        //let clocks = rcc.cfgr.freeze();
        rprintln!("clocks:");
        rprintln!("hclk {}", _clocks.hclk().0);

        // Configure SPI
        let sck = gpiob.pb10.into_alternate_af5();
        let miso = gpioc.pc2.into_alternate_af5();
        let mosi = gpioc.pc3.into_alternate_af5();
        let cs = gpiob.pb12.into_push_pull_output().set_speed(Speed::High);

        let spi = Spi::spi2(
            ctx.device.SPI2,
            (sck, miso, mosi),
            MODE_3,
            stm32f4xx_hal::time::KiloHertz(2000).into(),
            _clocks,
        );

        let delay_or_something = DwtDelay::new(&mut core.DWT, _clocks);
        let mut pmw3389 = pmw3389::Pmw3389::new(spi, cs, delay_or_something).unwrap();

        // set in burst mode
        let _burst = pmw3389.write_register(Register::MotionBurst, 0x00);
        // /\/\/\/\/\
        // ||||||||||
        // Sensor Init

        // USB
        // ||||||||||
        // \/\/\/\/\/

        // Pull the D+ pin down to send a RESET condition to the USB bus.
        // Dose not work yet.
        //let mut usb_dp = gpioa.pa12.into_alternate_af10();
        //usb_dp= false;
        //delay(_clocks.sysclk().0 / 100);

        let usb = USB {
            usb_global: ctx.device.OTG_FS_GLOBAL,
            usb_device: ctx.device.OTG_FS_DEVICE,
            usb_pwrclk: ctx.device.OTG_FS_PWRCLK,
            pin_dm: gpioa.pa11.into_alternate_af10(),
            pin_dp: gpioa.pa12.into_alternate_af10(),
        };

        USB_BUS.replace(UsbBus::new(usb, EP_MEMORY));
        
        let hid = HIDClass::new(USB_BUS.as_ref().unwrap(), NuttaliReport::desc(), 1);
        let usb_dev = UsbDeviceBuilder::new(USB_BUS.as_ref().unwrap(), UsbVidPid(0xc410, 0x0000))
            .manufacturer("Nuttali")
            .product("Mouse")
            .serial_number("1.0")
            .device_class(0)
            .build();
        
        // /\/\/\/\/\
        // ||||||||||
        // USB
        
        init::LateResources{led_blue, led_red, led_green, dpi_button, left_button, right_button, scroll_button, backward_button, forward_button, hid, usb_dev, pmw3389, scroll_B, scroll_A}
    }

    #[task(binds=OTG_FS, resources = [led_blue, led_red, led_green, dpi_button, left_button, right_button, scroll_button, backward_button, forward_button, hid, usb_dev, pmw3389, scroll_A, scroll_B])]
    fn on_usb(ctx: on_usb::Context) {
        //The scroll wheel need to know the last position or dose not work.
        static mut A_PREV :bool = false;
        static mut B_PREV :bool = false;
        
        
        static mut DPI_BUTTON_PREV: bool = false;
        
        static mut WRAPPING_LED_COUNTER:i32 = 0;
        
        // destruct the context
        let (led_blue, led_red, led_green, dpi_button,
            left_button, right_button, scroll_button, backward_button, 
            forward_button, usb_dev, hid, pmw3389, scroll_A, scroll_B) 
            = (ctx.resources.led_blue,ctx.resources.led_red,
               ctx.resources.led_green,ctx.resources.dpi_button,
               ctx.resources.left_button, ctx.resources.right_button,
               ctx.resources.scroll_button, ctx.resources.backward_button,
               ctx.resources.forward_button, ctx.resources.usb_dev, 
               ctx.resources.hid, ctx.resources.pmw3389, ctx.resources.scroll_A,
               ctx.resources.scroll_B);
        let a:bool = scroll_A.is_high().unwrap();
        let b:bool = scroll_B.is_high().unwrap();
        let wheel_count = check_scroll(a,b,*A_PREV,*B_PREV);
        *A_PREV = a;
        *B_PREV = b;
        
        // Read from sensor
        let (x_sensor, y_sensor) = pmw3389.read_status().unwrap();
        
        let left:bool = left_button.is_low().unwrap();
        let right:bool = right_button.is_low().unwrap();
        let scroll:bool = scroll_button.is_high().unwrap();
        let backward:bool = backward_button.is_high().unwrap();
        let forward:bool = forward_button.is_high().unwrap();

        let report = NuttaliReport {
            x: (x_sensor as i8)>> 1, // need to convert form i16 to i8. Shifts to get smother movement
            y: (y_sensor as i8)>> 1, // need to convert form i16 to i8. Shifts to get smother movement
            buttons: check_buttons(left, right, scroll, backward, forward), // (into takes a bool into an integer)
            wheel: wheel_count,
        };

        
        if dpi_button.is_high().unwrap() && *DPI_BUTTON_PREV == false{
            *WRAPPING_LED_COUNTER = *WRAPPING_LED_COUNTER + 1;
            let (red,blue,green) = change_led(*WRAPPING_LED_COUNTER);
            if red{
                led_red.set_high().ok();
            }else{
                led_red.set_low().ok();
            }
            if blue{
                led_blue.set_high().ok();
            }else{
                led_blue.set_low().ok();
            }
            if green{
                led_green.set_high().ok();
            }else{
                led_green.set_low().ok();
            }
        }
        *DPI_BUTTON_PREV = dpi_button.is_high().unwrap();

        // push the report
        hid.push_input(&report).ok();

        // update the usb device state
        if usb_dev.poll(&mut [hid]) {
            return;
        }
    }

    #[idle]
    fn idle(_cx: idle::Context) -> ! {
        rprintln!("idle");
        loop {
            continue;
        }
    }
};

fn check_scroll(scroll_a:bool, scroll_b:bool, scroll_a_prev:bool, scroll_b_prev:bool) -> i8{
    let mut wheel_count: i8 = 0;

    if scroll_a != scroll_a_prev || scroll_b != scroll_b_prev{

        //Sequence for up:
        //A:Low  B:Low
        //A:High B:Low
        //B:High B:High
        //A:Low  B:High
        //A:Low  B:Low

        //Sequence for down:
        //A:Low  B:Low
        //A:Low  B:High
        //A:High B:High
        //A:High B:Low
        //A:Low  B:Low

        if scroll_a_prev==scroll_b_prev{
            if scroll_b==scroll_b_prev{
                wheel_count +=1;
                rprintln!("Up count:{}", wheel_count)
            }else{
                wheel_count -=1;
                rprintln!("Down count:{}", wheel_count)
            }
        }else{
            if scroll_a==scroll_a_prev{
                wheel_count +=1;
                rprintln!("Up count:{}", wheel_count)
            }else{
                wheel_count -=1;
                rprintln!("Down count:{}", wheel_count)
            }
        }
    }
    return wheel_count;
}

//Dose not check dpi
// Left button : bit no 0
// Right button : bit no 1
// Scroll/Middle button : bit no 2
// Backward button : bit no 3
// Forward button : bit no 4
fn check_buttons(left:bool,right:bool,scroll:bool,backward:bool,forward:bool) -> u8{
    let mut result:u8 = 0;
    if left{
        result += 1;
    }
    if right{
        result += 2;
    }
    if scroll{
        result += 4;
    }
    if backward{
        result += 8;
    }
    if forward{ 
        result += 16;
    }
    return result;
}

fn change_led(no_toggled: i32) -> (bool,bool,bool) {
    let led_red:bool;
    let led_blue:bool;
    let led_green:bool;

    if no_toggled % 8 == 0{
        led_red= true;
        led_green= true;
        led_blue= true;
    } else if no_toggled % 8 == 1{
        led_red= true;
        led_blue= false;
        led_green= true;
    } else if no_toggled % 8 == 2{
        led_red= true;
        led_blue= true;
        led_green= false;
    } else if no_toggled % 8 == 3{
        led_red= false;
        led_blue= true;
        led_green= true;
    } else if no_toggled % 8 == 4{
        led_red= true;
        led_blue= false;
        led_green= false;
    } else if no_toggled % 8 == 5{
        led_red= false;
        led_blue= false;
        led_green= true;
    } else if no_toggled % 8 == 6{
        led_red= false;
        led_blue= true;
        led_green= false;
    } else {
        led_red= false;
        led_blue= false;
        led_green= false;
    }
    return (led_red,led_blue,led_green);
}

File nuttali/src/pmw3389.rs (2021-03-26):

/// PWM3389 gaming mouse sensor driver
use stm32f4xx_hal::prelude::*;

use crate::DwtDelay;

use embedded_hal::blocking::spi::{Transfer, Write};
use embedded_hal::digital::v2::OutputPin;

use rtt_target::{rprintln};

#[allow(dead_code)]
#[derive(Clone, Copy)]
pub enum Register {
    ProductId = 0x00,
    RevisionId = 0x01,
    Motion = 0x02,
    DeltaXL = 0x03,
    DeltaXH = 0x04,
    DeltaYL = 0x05,
    DeltaYH = 0x06,
    SQUAL = 0x07,
    RawDataSum = 0x08,
    MaximumRawdata = 0x09,
    MinimumRawdata = 0x0A,
    ShutterLower = 0x0B,
    ShutterUpper = 0x0C,
    RippleControl = 0x0D,
    ResolutionL = 0x0E,
    ResolutionH = 0x0F,
    Config2 = 0x10,
    AngleTune = 0x11,
    FrameCapture = 0x12,
    SROMEnable = 0x13,
    RunDownshift = 0x14,
    Rest1RateLower = 0x15,
    Rest1RateUpper = 0x16,
    Rest1Downshift = 0x17,
    Rest2RateLower = 0x18,
    Rest2RateUpper = 0x19,
    Rest2Downshift = 0x1A,
    Rest3RateLower = 0x1B,
    Rest3RateUpper = 0x1C,
    Observation = 0x24,
    DataOutLower = 0x25,
    DataOutUpper = 0x26,
    RawDataDump = 0x29,
    SROMId = 0x2A,
    MinSQRun = 0x2B,
    RawDataThreshold = 0x2C,
    Control2 = 0x2D,
    Config5L = 0x2E,
    Config5H = 0x2F,
    PowerUpReset = 0x3A,
    Shutdown = 0x3B,
    InverseProductID = 0x3F,
    LiftCutoffTune3 = 0x41,
    AngleSnap = 0x42,
    LiftCutoffTune1 = 0x4A,
    MotionBurst = 0x50,
    LiftCutoffTune1Timeout = 0x58,
    LiftCutoffTune1MinLength = 0x5A,
    SROMLoadBurst = 0x62,
    LiftConfig = 0x63,
    RawDataBurst = 0x64,
    LiftCutoffTune2 = 0x65,
    LiftCutoffTune2Timeout = 0x71,
    LiftCutoffTune2MinLength = 0x72,
    PWMPeriodCnt = 0x73,
    PWMWidthCnt = 0x74,
}

impl Register {
    fn addr(self) -> u8 {
        self as u8
    }
}

pub struct Pmw3389<SPI, CS> {
    spi: SPI,
    cs: CS,
    delay: DwtDelay,
}

impl<SPI, CS, E> Pmw3389<SPI, CS>
where
    SPI: Transfer<u8, Error = E> + Write<u8, Error = E>,
    CS: OutputPin,
{
    fn com_begin(&mut self) {
        self.cs.set_low().ok();
    }

    fn com_end(&mut self) {
        self.cs.set_high().ok();
    }

    /// Creates a new driver from a SPI peripheral and a NCS pin
    pub fn new(spi: SPI, cs: CS, delay: DwtDelay) -> Result<Self, E> {
        let mut pmw3389 = Pmw3389 { spi, cs, delay };

        rprintln!("pmw3389 - new");

        // ensure SPI is reset
        pmw3389.com_end();
        pmw3389.delay.delay_us(40);
        pmw3389.com_begin();
        pmw3389.delay.delay_us(40);
        pmw3389.com_end();

        // read product id
        let id = pmw3389.product_id()?;
        rprintln!("product_id 0x{:x}", id);

        let srom_id = pmw3389.read_register(Register::SROMId)?;
        rprintln!("srom_id {}, 0x{:x}", srom_id, srom_id);

        rprintln!("reset");

        // shutdown

        // adns_write_reg(Shutdown, 0xb6); // Shutdown first
        // delay(300);

        // adns_com_begin(); // drop and raise ncs to reset spi port
        // delayMicroseconds(40);
        // adns_com_end();
        // delayMicroseconds(40);

        // pmw3389.write_register(Register::Shutdown, 0xb6)?;
        // pmw3389.delay.delay_ms(300);
        // pmw3389.com_begin();
        // pmw3389.delay.delay_us(40);
        // pmw3389.com_end();
        // pmw3389.delay.delay_us(40);

        // force reset
        pmw3389.write_register(Register::PowerUpReset, 0x5a)?;

        // wait for reboot
        pmw3389.delay.delay_ms(50);

        // read product id
        let id = pmw3389.product_id()?;
        rprintln!("product_id 0x{:x}", id);

        let srom_id = pmw3389.read_register(Register::SROMId)?;
        rprintln!("srom_id {}, 0x{:x}", srom_id, srom_id);

        // read registers 0x02 to 0x06 (and discard the data)
        pmw3389.read_register(Register::Motion)?;
        pmw3389.read_register(Register::DeltaXL)?;
        pmw3389.read_register(Register::DeltaXH)?;
        pmw3389.read_register(Register::DeltaYL)?;
        pmw3389.read_register(Register::DeltaYH)?;

        pmw3389.upload_firmware()?;

        pmw3389.delay.delay_ms(1000);

        rprintln!("Optical Chip Initialized");

        // read product id
        let id = pmw3389.product_id()?;
        rprintln!("product_id 0x{:x}", id);

        let srom_id = pmw3389.read_register(Register::SROMId)?;
        rprintln!("srom_id {}, 0x{:x}", srom_id, srom_id);

        Ok(pmw3389)
    }

    pub fn read_register(&mut self, reg: Register) -> Result<u8, E> {
        self.com_begin();

        let mut buffer = [reg.addr() & 0x7f];
        self.spi.transfer(&mut buffer)?;

        // tSRAD
        self.delay.delay_us(35);

        let mut buffer = [0];
        self.spi.transfer(&mut buffer)?;

        // tSCLK-NCS for read operation is 120ns
        self.delay.delay_us(1);

        self.com_end();

        // tSRW/tSRR (=20us) minus tSCLK-NCS
        self.delay.delay_us(19);

        Ok(buffer[0])
    }

    pub fn write_register(&mut self, reg: Register, byte: u8) -> Result<(), E> {
        self.com_begin();

        let mut buffer = [reg.addr() | 0x80];
        self.spi.transfer(&mut buffer)?;

        // send
        let mut buffer = [byte];
        self.spi.transfer(&mut buffer)?;

        // tSCLK-NCS for write operation
        self.delay.delay_us(20);

        self.com_end();
        // tSWW/tSWR (=120us) minus tSCLK-NCS.
        // Could be shortened, but is looks like a safe lower bound

        self.delay.delay_us(100);

        Ok(())
    }

    /// Reads the ProductId register; should return `0x47`
    pub fn product_id(&mut self) -> Result<u8, E> {
        self.read_register(Register::ProductId)
    }

    /// Read status
    pub fn read_status(&mut self) -> Result<(i16, i16), E> {
        self.com_begin();

        self.spi.transfer(&mut [Register::MotionBurst.addr()])?;

        self.delay.delay_us(35); // waits for tSRAD

        // read burst buffer
        let mut buf = [0u8; 12];
        self.spi.transfer(&mut buf)?;

        // tSCLK-NCS for read operation is 120ns
        // self.delay.delay_us(120);

        self.com_end();
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

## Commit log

2021-02-03 Added a .gitignore for Rust and KiCad.
2021-02-03 created pmw
    [MCU.sch, Nuttali.sch, file601B1424.sch]
2021-02-04 Small changes on PMW
    [Nuttali.sch, file601B1424.sch]
2021-02-04 Fixed MCU
    [MCU.sch, Nuttali.sch, USB_and_Power.sch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]
2021-02-04 Fixed power and USB
    [MCU.sch, USB_and_Power.sch]
2021-02-05 Added buttons
    [ButtonsAndWheel.sch, MCU.sch, Nuttali.sch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]
2021-02-05 Added scroolWheel and rgb
    [ButtonsAndWheel.sch]
2021-02-10 some footprints fixed
    [ButtonsAndWheel.sch, MCU.sch, Nuttali.sch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]
2021-02-10 all footprints fixed
    [ButtonsAndWheel.sch, MCU.sch, file601B1424.sch]
2021-02-10 First draft of the pcb
    [ButtonsAndWheel.sch, MCU.sch, Nuttali.kicad_pcb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]
2021-02-11 Working on the new pcb
    [ButtonsAndWheel.sch, Nuttali.kicad_pcb]
2021-02-12 Soon done with the pcb
    [Nuttali.kicad_pcb, USB_and_Power.sch]
2021-02-12 created foot print for encoder
2021-02-12 pushing a few things
    [Nuttali.kicad_pcb]
2021-02-13 extended the pcb board with 2 mm to right
    [ButtonsAndWheel.sch, MCU.sch, Nuttali.kicad_pcb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]
2021-02-13 footprint for omron switches done
2021-02-13 Fixed almost all footprints and nearly the layout of the pcb
    [ButtonsAndWheel.sch, USB_and_Power.sch, Version1.kicad_pcb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]
2021-02-13 Missed saving things
    [Nuttali.kicad_pcb]
2021-02-14 Finnished the pcb
    [ButtonsAndWheel.sch, MCU.sch, Nuttali.kicad_pcb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]
2021-02-14 Finnished design.
    [ButtonsAndWheel.sch, MCU.sch, Nuttali.kicad_pcb]
2021-02-14 Changed routes on the scroll wheel button
    [ButtonsAndWheel.sch, Nuttali.kicad_pcb]
2021-02-14 Chnages footprint of esd
    [Nuttali.kicad_pcb]
2021-02-14 SideButton Nya Knappar
    [Untitled.kicad_pcb, Untitled.sch]
2021-02-14 Last push befor ordering
    [ButtonsAndWheel.sch, MCU.sch, Nuttali.kicad_pcb]
2021-02-14 PCB done
    [Nuttali.kicad_pcb, USB_and_Power.sch]
2021-03-15 added pers things to project
    [ButtonsAndWheel.sch, MCU.sch, USB_and_Power.sch]
2021-03-19 added some things
    [ButtonsAndWheel.sch, MCU.sch, Nuttali.kicad_pcb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]
2021-03-22 All buttons are registering but scroll forward and backwards needs tuning. No anti button bouncing implemented.
2021-03-23 Left and right button working. Started integrating the sensor code.
2021-03-23 Updated with the sensor, it's working but have some issues. Might need to change protocol.
    [usb-mouse.rs]
2021-03-24 got the sensor, scroll and left button to work on windows.
2021-03-24 lowerd the speed of the sensor
2021-03-24 Added usb_mouse as a new file to avoid merge conflicts and loss of data. DPI button and rgb working.
2021-03-25 pcb version 2
2021-03-25 verion 3 pcb
2021-03-25 pcb support
